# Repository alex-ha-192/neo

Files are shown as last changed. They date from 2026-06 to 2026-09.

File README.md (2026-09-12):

# Neo
 
The Neo buzzer system is an open-source, hopefully reliable, and hopefully affordable line of quiz lockout buzzers. It also does not currently exist. This is a rather significant flaw, though one I'm working to repair.

The initial planning is for one set of buzzers intended to have user-facing backwards compatibility with a popular set of commercial buzzers. A cheaper option may follow depending on how that goes.

## Progress

### Classic v1

- [x] Finalise design concepts
- [x] Source parts
- [ ] PCB design
- [ ] Order and initial testing
- [ ] 3D printed case design
- [ ] Real-world testing
- [ ] Release

## Pricing

I'm trying to be cost-conscious while designing these buzzers, but I'm not planning on imminently selling any or distributing them beyond Imperial until they're both finished and well-tested. If you need a buzzer set now, I'll point you to buying a [Kitsune system](https://github.com/Amekyras/kitsune) from [Aisling Skeet](https://github.com/Amekyras); they're a solid set of buzzers and they've been tested at quite a few competitive events. If you want a pricing estimate, it's probably whatever I say it is at the moment plus a bit on top because this keeps getting more expensive with every revision.

Just a quick note as well, this is an open-source project and, as a result, you can do whatever you'd like as per the [licence](LICENCE), but if you want to make your own buzzers, please don't sell them? Obviously I neither can nor will try and stop you, but these haven't been particularly cheap to work on, even though as I write this I haven't shipped out any PCBs yet - parts are expensive! I'd love it if anyone who wants to improve them does that though, either on this repository or on your own fork.

## Features (planned, WIP)

### Classic v1.0

- Daisy-chain as many buzzers per side as you could ever reasonably want
- USB-C connection with data for potential [BuzzIn.live](https://buzzin.live) support or generic input
- Low/fair latency
- Static discharge protection and industrial signalling for reliability
- At-home reflashable central unit firmware for customisation/DIY firmware upgrades
- Open source!

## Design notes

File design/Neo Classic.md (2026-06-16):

# Control unit
- Based around STM32
- Features a RESET button and 4 LEDs for each team
- One DMX/XLR5 port on each side for buzzer daisy chain

# Buzzers
- Based around an ATTiny or similar
- One male and one female DMX/XLR5 port on each side
- Features a button and an LED

# Communication
- Enumeration takes place over I2C/UART/Serial or something really basic - needs to run on RESET (and therefore RESET must be pressed before a game - initialise the LEDs to ON on the control unit)
- Switch to RS485 after enumeration for minimal latency
- Termination resistor in control unit only, hope for the best

# Buttons
- Use mechanical keyboard switches with minimal capacitor debounce to reduce latency
- Either use standard keycaps or 3D print "buzzer button"-style caps

# Parts List
- DMX/XLR5: https://cpc.farnell.com/cliff-electronic-components/fc61955/xlr-plug-5-pole-panel-mount-black/dp/CN22651, https://cpc.farnell.com/cliff-electronic-components/fc61950/xlr-socket-5-pole-p-mount-latch/dp/CN22650, https://cpc.farnell.com/pulse/pls00408/lead-xlr-dmx-5p-2pair-0-5m/dp/AV22551
- RS485 board: https://www.aliexpress.com/item/1005009552330016.html
- Gateron Jupiter Red keyboard switches: https://mechboards.co.uk/products/gateron-jupiter-red-switches
- MX/Kailh hotswap sockets: https://mechboards.co.uk/products/kailh-hotswap-sockets
- Shift register for LEDs: https://www.digikey.co.uk/en/products/detail/texas-instruments/SN74HC595DR/562919
- STM32: https://www.digikey.co.uk/en/products/detail/stmicroelectronics/STM32C552CET6/29220413
- 5V to 3V3 regulator: https://www.mouser.co.uk/ProductDetail/Diodes-Incorporated/AZ1117CH2-3.3TRG1?qs=lQAVKuKFhkLc7jCxso2G3w%3D%3D

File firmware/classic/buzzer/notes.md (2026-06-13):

# Possible serial library for enumeration?
https://docs.arduino.cc/learn/built-in-libraries/software-serial/

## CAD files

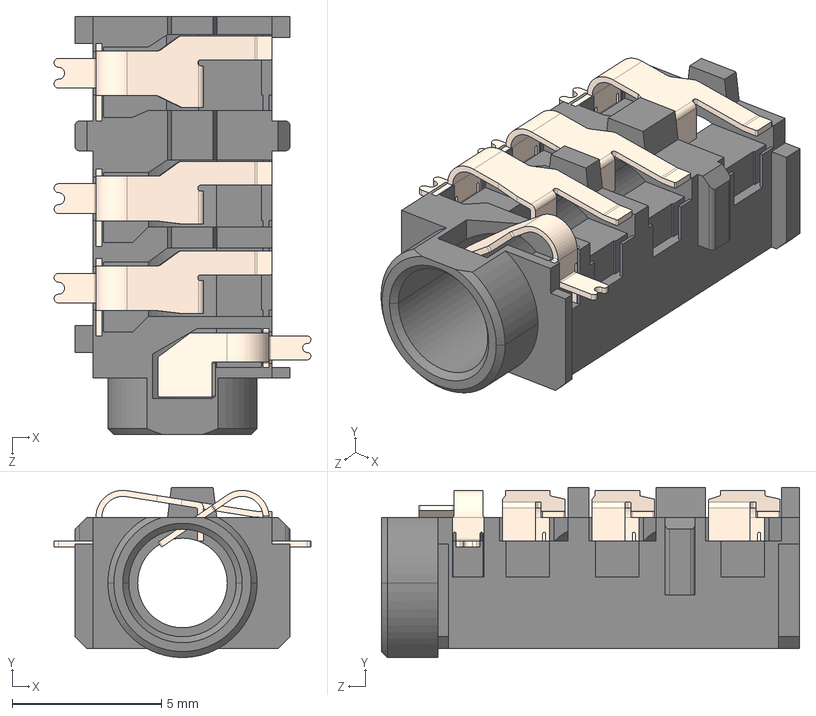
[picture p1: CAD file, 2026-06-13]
kicad/imports/Keebio-Parts.pretty-master/3dmodels/CUI_SJ-43614-SMT-TR.step
8.60 x 5.70 x 14.0 mm

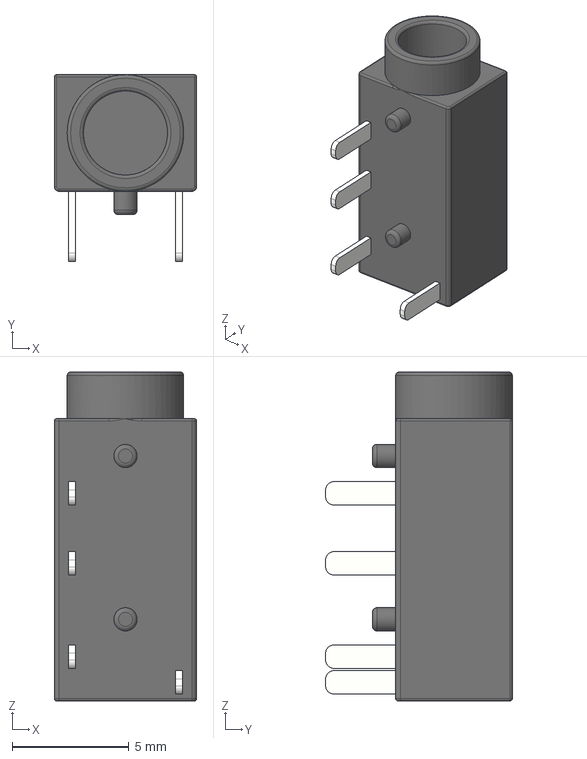
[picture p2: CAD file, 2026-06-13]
kicad/imports/Keebio-Parts.pretty-master/3dmodels/PJ-320A.step
6.10 x 8.00 x 14.1 mm

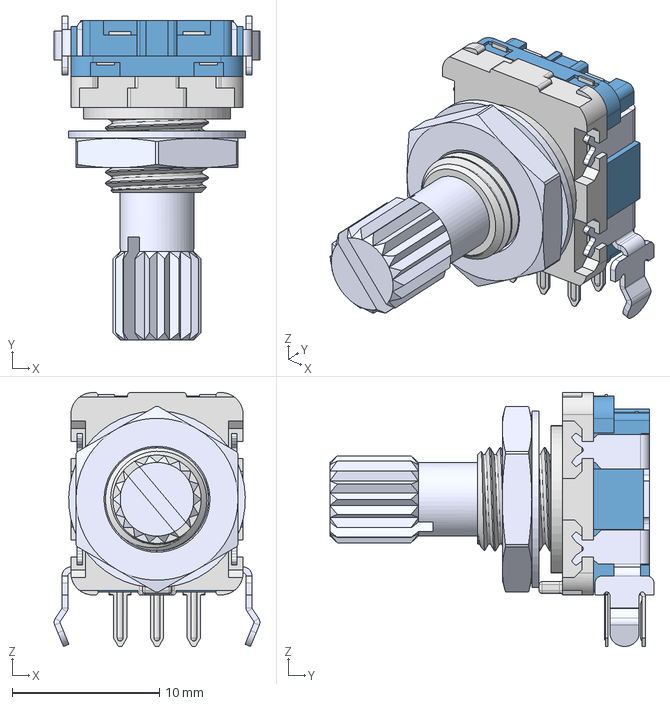
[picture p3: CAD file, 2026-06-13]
kicad/imports/Keebio-Parts.pretty-master/3dmodels/EC11B-SW-Horiz-15K-blue.step
14.0 x 22.0 x 17.3 mm

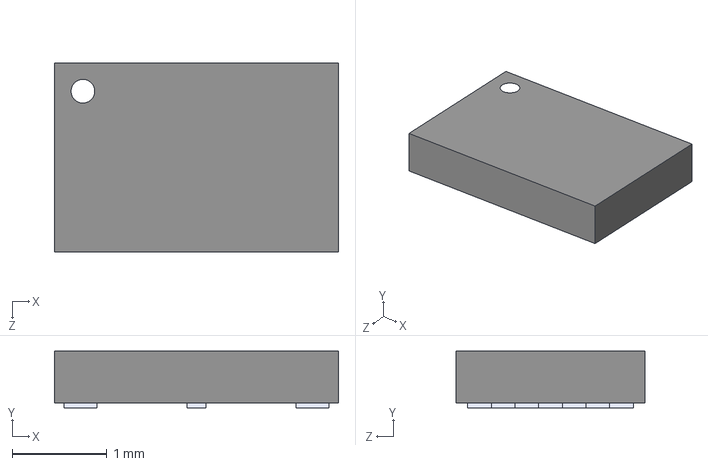
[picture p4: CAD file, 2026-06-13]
kicad/imports/Keebio-Parts.pretty-master/3dmodels/W25Q16JVUXIQ.step
3.00 x 0.6 x 2.00 mm

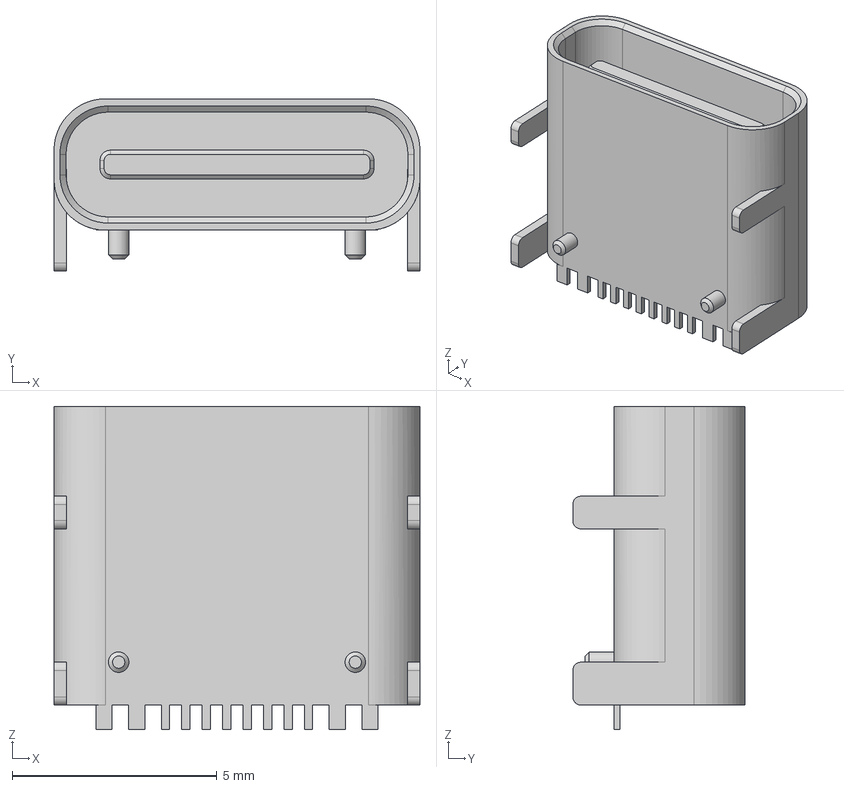
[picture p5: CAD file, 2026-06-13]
kicad/imports/Keebio-Parts.pretty-master/3dmodels/HRO TYPE-C-31-M-12.step
8.94 x 4.21 x 7.90 mm

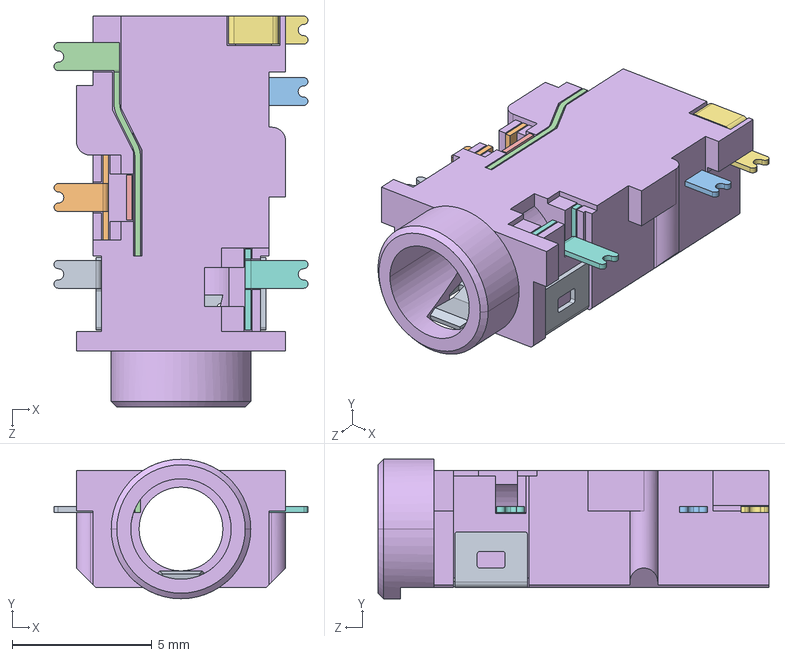
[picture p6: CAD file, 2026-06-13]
kicad/imports/Keebio-Parts.pretty-master/3dmodels/CUI_DEVICES_SJ-43504-SMT-TR.step
9.10 x 5.00 x 14.0 mm

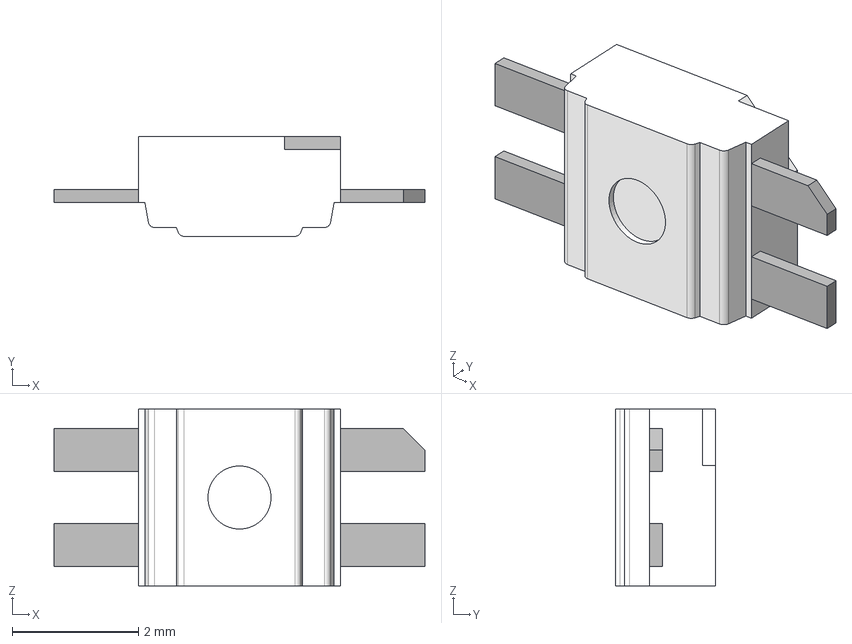
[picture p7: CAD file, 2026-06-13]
kicad/imports/Keebio-Parts.pretty-master/3dmodels/SK6812MINI-E v1.step
5.88 x 1.58 x 2.80 mm

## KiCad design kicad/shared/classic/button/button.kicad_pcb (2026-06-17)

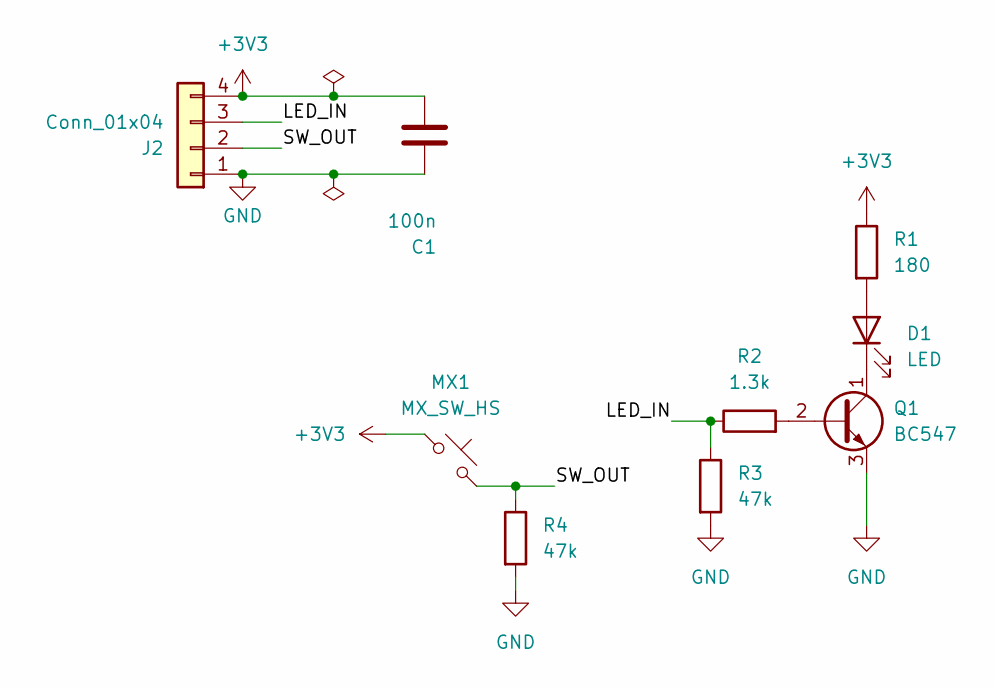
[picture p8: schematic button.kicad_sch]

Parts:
C1: 100n; C_0805_2012Metric
D1: LED; LED_D5.0mm
J2: Conn_01x04; JST_XA_B04B-XASK-1-A_1x04_P2.50mm_Vertical
MX1: MX_SW_HS; SW_MX_HS_CPG151101S11_1u
Q1: BC547; TO-92_Inline
R1: 180; R_0805_2012Metric
R2: 1.3k; R_0805_2012Metric
R3, R4: 47k; R_0805_2012Metric

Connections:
+3V3: C1.2, J2.4, MX1.1, R1.1
/LED_IN: J2.3, R2.1, R3.1
/SW_OUT: J2.2, MX1.2, R4.1
GND: C1.1, J2.1, Q1.3 (E), R3.2, R4.2
unnamed: D1.2 (A), R1.2
unnamed: D1.1 (K), Q1.1 (C)
unnamed: Q1.2 (B), R2.2

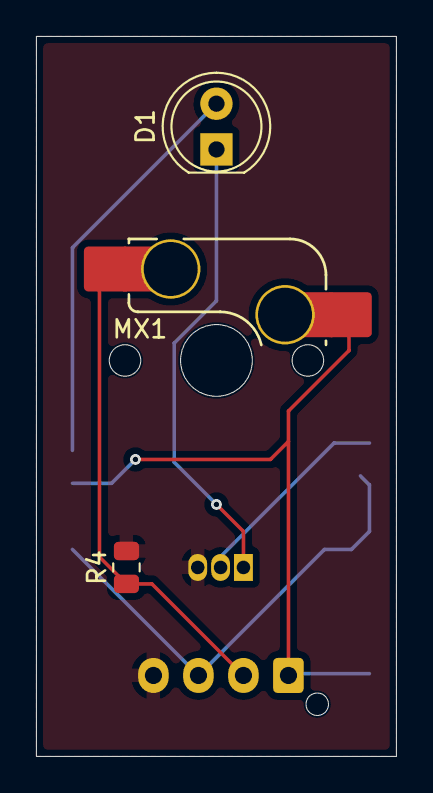
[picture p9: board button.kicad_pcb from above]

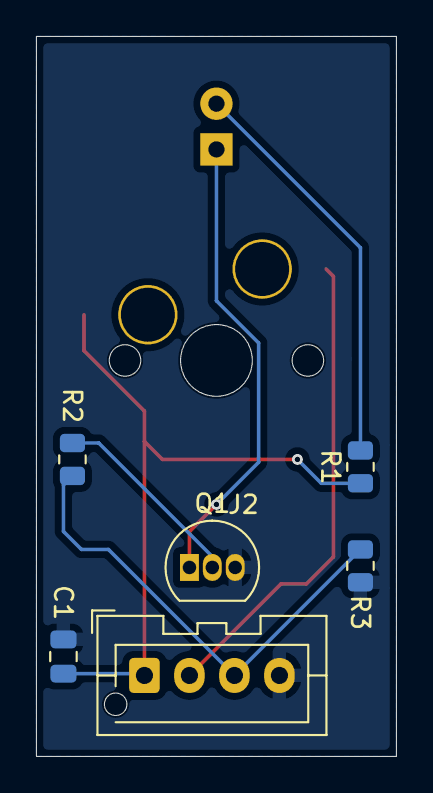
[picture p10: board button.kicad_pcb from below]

Board: 2 copper layers, 20.0 x 40.0 mm, 9 parts (6 on the bottom side), 7 nets.

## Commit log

2026-06-10 Approximate BoM for really basic buzzers
2026-06-10 More BoM detail
2026-06-12 Added template KiCAD projects for all PCBs for Classic/Lite
    [button.kicad_pcb, button.kicad_sch, connector.kicad_pcb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]
2026-06-12 refactor pcb structure
    [button.kicad_pcb, button.kicad_sch, connector.kicad_pcb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]
2026-06-12 Added keyboard switch parts
2026-06-12 Added male/female connector assembly PCB templates
    [female.kicad_pcb, female.kicad_sch, male.kicad_pcb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]
2026-06-13 Draft of Classic button/LED assembly
    [CUI_DEVICES_SJ-43504-SMT-TR.step, CUI_SJ-43614-SMT-TR.step, EC11B-SW-Horiz-15K-blue.step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]
2026-06-13 Decoupling cap and JST-XA connector for Classic button daughterboard
    [button.kicad_pcb, button.kicad_sch]
2026-06-14 Pulldown for the switch bc I'm dumb
    [button.kicad_pcb, button.kicad_sch]
2026-06-14 feat: created LED board schematic for the Classic control unit (8 LEDs) using 74HC595 shift register, measurements needed for actual PCB
    [led.kicad_sch]
2026-06-15 Button/LED assembly Classic actually does the thing properly now
    [button.kicad_pcb, button.kicad_sch]
2026-06-16 Power supply for STM32 for Classic control unit
    [main.kicad_sch]
2026-06-16 More stuff for Classic control unit
    [led.kicad_sch, main.kicad_sch]
2026-06-16 fix: Changed Classic control unit MCU and expanded schematic
    [main.kicad_sch]
2026-06-17 feat: Cleaned up pin arrangement for Classic button/LED assembly, added connector for that on Classic control unit main board, added pins for STM32 TODO
    [button.kicad_pcb, button.kicad_sch, main.kicad_sch]
2026-06-17 fix: ESD earthing stuff etc. for HW-0519
    [main.kicad_sch]
2026-06-17 feat: Stuff for STM32 programming later
    [main.kicad_sch]
2026-06-17 feat: Added main Classic buzzer board; now basically just waiting on XLR5 and HW-0519 footprints; also need to see if I need a separate earth for the HW-0519s on the buzzer boards
    [button.kicad_sch, main.kicad_sch]
2026-06-18 feat: Added connector schematics and fixed some other connectors in other schematics
    [female.kicad_sch, led.kicad_sch, main.kicad_sch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]
2026-06-23 Added ESD protection for USB/RS485, not for serial lines yet; harmonised XLR pin numbers between boards
    [female.kicad_sch, main.kicad_sch, male.kicad_sch]
2026-06-23 Added some stuff for ESD protection on the serial lines; redid the STM32 programming pins
    [female.kicad_sch, main.kicad_sch, male.kicad_sch]
2026-06-27 feat: Should be able to footprint and route some prototype boards to see if I'm not totally off-base here
    [button.kicad_sch, female.kicad_sch, led.kicad_sch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]
2026-09-12 Added protection cap to Classic buzzer mainboard
    [main.kicad_sch]
2026-09-12 Update README to reflect current project status
    Removed completed PCB and CAD model sections from the README.
